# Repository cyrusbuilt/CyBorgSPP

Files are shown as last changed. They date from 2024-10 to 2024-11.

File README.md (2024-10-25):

# CyBorgSPP
Standard Parallel (Printer) Port adapter for [CyBorg](https://github.com/cyrusbuilt/CyBorg).

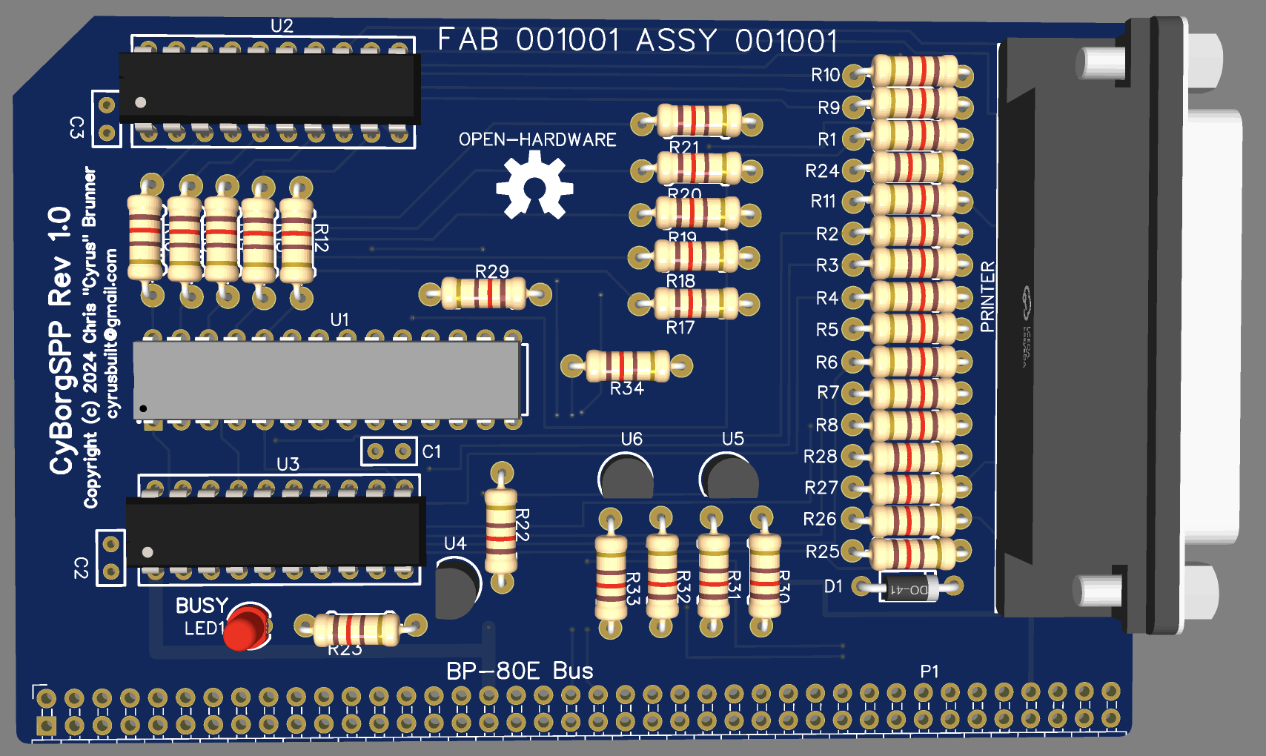
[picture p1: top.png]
CyBorgSPP


This is the first add-on card for CyBorg. The goal of this board is to provide an at least *somewhat* [IEEE 1284](https://en.wikipedia.org/wiki/IEEE_1284)-compliant parallel port interface. This board is currently only intended to operate in SPP (a.k.a. "Centronics" or "Compatibility") mode though it is possible to support other modes in via firmware modification (such as Nibble Mode). This board does not have an onboard MCU or any firmware of its own but instead relies on host firmware support.

## Implementation
This board is actually one of a few possible implementations of a parallel port for CyBorg:

1) Using a [Z80 PIO Chip](http://www.z80.info/zip/z80piomn.pdf). This would be a more "conventional" approach.

2) Using the I/O expansion lines (pins 41-56) of CyBorg's BP-80E bus. Pros: Eliminates a bunch of extra circuitry and the need for the 3.3V rail and would not consume an I2C address. Cons: Once initialized, CyBorg's IOEXP chip (and therefore *all* of the I/O expansion lines) on CyBorg's bus would become dedicated to the parallel (printer) port, which could interfere with the operation of any other boards on the bus that rely on those pins. At least until CyBorg is rebooted. There is also no easy way to detect whether or not the card is installed.

3) Using the I2C bus and a separate MCP23017 chip in conjunction with the rest of the SPP circuitry. Pros: Eliminates the reliance on CyBorg's onboard IOEXP and therefore doesn't need any of those I/O pins, so there is no interference with their operation. This also easy to detect whether or not the card is installed. Cons: Currently uses a fixed I2C address of 0x21 which means no other I2C device on the bus can be configured to use that address. However, this *does* essentially make the device 'plug and play' because this address would be known to CyBorg's firmware and therefore make it easy to detect if the card is installed and configure it.

This board went with option 3. It's worth noting that options 2 and 3 are a less direct route to implementing a parallel port since there are some additional steps that have to be taken vs. using a PIO chip. However, the performance *should* still be on par.

## Theory of Operation
On boot, CyBorg's firmware checks to see if CyBorgSPP is installed, and if so, enables support for it. If enabled, the following OpCodes become avaialable:

- OP_SPP_WR_INIT (0x11): Initialize the board. This really only needs to be done *once* sometime after boot before using any other related OpCodes.

- OP_SPP_WR_WRITE (0x12): Sends a byte to the printer. It's worth noting that this operation doesn't check the READY status of the printer beforehand so you should read status first to determine that if needed.

- OP_SPP_RD_READ (0x8A): Reads the status of the printer.

When an application writes one of the supported OpCodes to the Z80 bus, ViCREM's Virtual I/O engine intercepts it and then sends the appropriate I2C transactions to CyBorgSPP to carry out the requested operation.

## Form Factor
This board is currently in an [RC2014](https://rc2014.co.uk/1377/module-template/) form-factor, though this is subject to change since CyBorg was designed to be ATX-compliant. CyBorgSPP's form-factor will likely change to something similar to an ISA or PCI card with mounting holes for the slot plate, etc.

## Firmware
Support for CyBorgSPP is built-in to CyBorg's firmware running on the [ViCREM](https://github.com/cyrusbuilt/CyBorg-Northbridge) chip.

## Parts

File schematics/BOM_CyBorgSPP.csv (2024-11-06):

ID | Name | Designator | Footprint | Quantity | Manufacturer Part | Manufacturer | Supplier | Supplier Part | Price
1 | BP-80E Bus | P1 | PIN_HEADER_ANGLED_2X40_PITCH2.54MM | 1 | ReliaPro | 2.54mm 1x40T Female header | LCSC | C3410 | 0.313
2 | 4k7 | R34,R24,R25,R26,R27,R28,R29 | PKG-0.25W RESISTOR | 7 | MCF 0.25W 150R | MULTICOMP | Element14 | 9339175
3 | MCP23017-E/SP | U1 | DIP-28_L35.0-W6.5-P2.54-LS7.6-BL | 1 | MCP23017-E/SP | Microchip Tech | LCSC | C647352 | 1.751
4 | SN74LS244N | U3,U2 | DIP-20_L25.5-W10.0-P2.54-LS7.6-BL | 2 | SN74LS244N | TI(德州仪器) | LCSC | C352965 | 0.542
5 | X0325FT17B2H | PRINTER | DSUB-TH_25P-P2.77_C3123041 | 1 | X0325FT17B2H | XKB Connectivity(中国星坤) | LCSC | C18723072 | 2.897
6 | 1N4001 | D1 | DO-41_BD2.4-L4.7-P8.70-D0.9-RD | 1 | 1N4001 | LRC | LCSC | C82804
7 | 2N7000_C3281848 | U4,U5,U6 | TO-92-3_L4.9-W3.7-P1.27-L | 3 | 2N7000 | DIOTEC(德欧泰克) | LCSC | C3281848 | 0.075
8 | 33 | R1,R2,R3,R4,R5,R6,R7,R8,R9,R10,R11 | PKG-0.25W RESISTOR | 11 | MCF 0.25W 150R | MULTICOMP | Element14 | 9339175
9 | 220 | R22 | PKG-0.25W RESISTOR | 1 | MCF 0.25W 150R | MULTICOMP | Element14 | 9339175
10 | 680 | R23 | PKG-0.25W RESISTOR | 1 | MCF 0.25W 150R | MULTICOMP | Element14 | 9339175
11 | 1k | R12,R13,R14,R15,R16 | PKG-0.25W RESISTOR | 5 | MCF 0.25W 150R | MULTICOMP | Element14 | 9339175
12 | 10k | R17,R18,R19,R20,R21,R30,R31,R32,R33 | PKG-0.25W RESISTOR | 9 | MCF 0.25W 150R | MULTICOMP | Element14 | 9339175
13 | 0.1uF | C1,C2,C3 | CAP-RAD-2.54MM | 3
14 | BUSY | LED1 | LED-TH_BD3.0-P2.54-FD | 1 | 204-10SURD/S530-A3 | EVERLIGHT(亿光) | LCSC | C99772 | 0.029

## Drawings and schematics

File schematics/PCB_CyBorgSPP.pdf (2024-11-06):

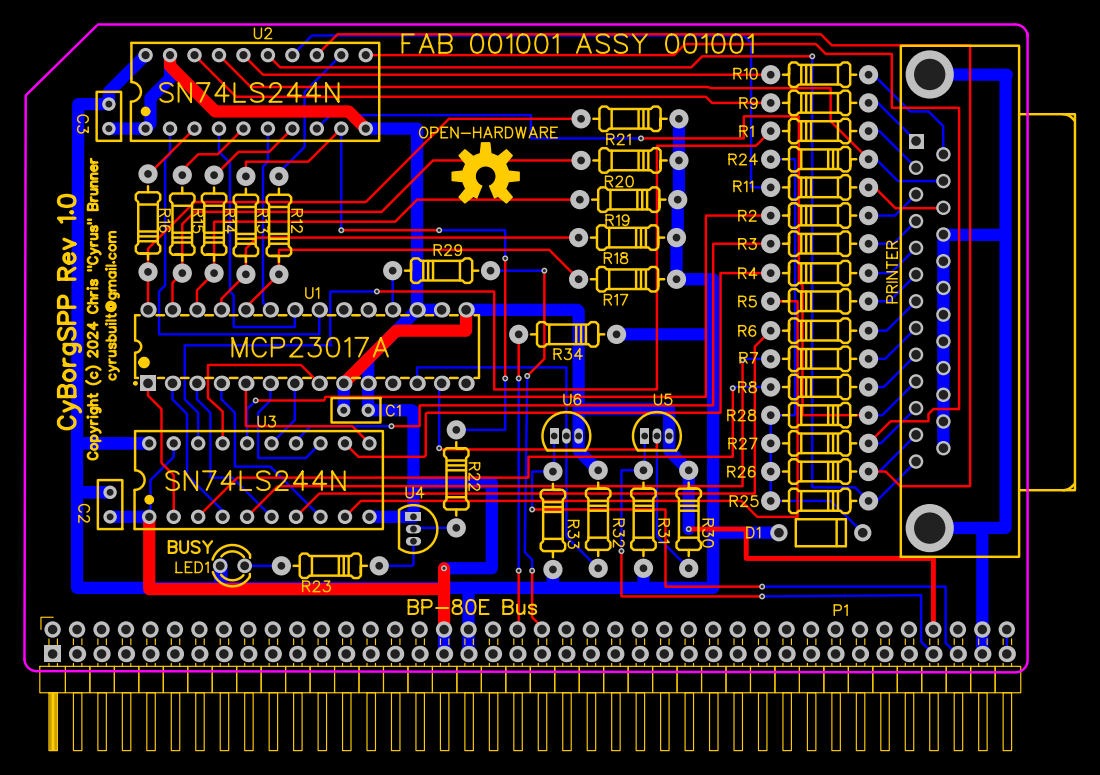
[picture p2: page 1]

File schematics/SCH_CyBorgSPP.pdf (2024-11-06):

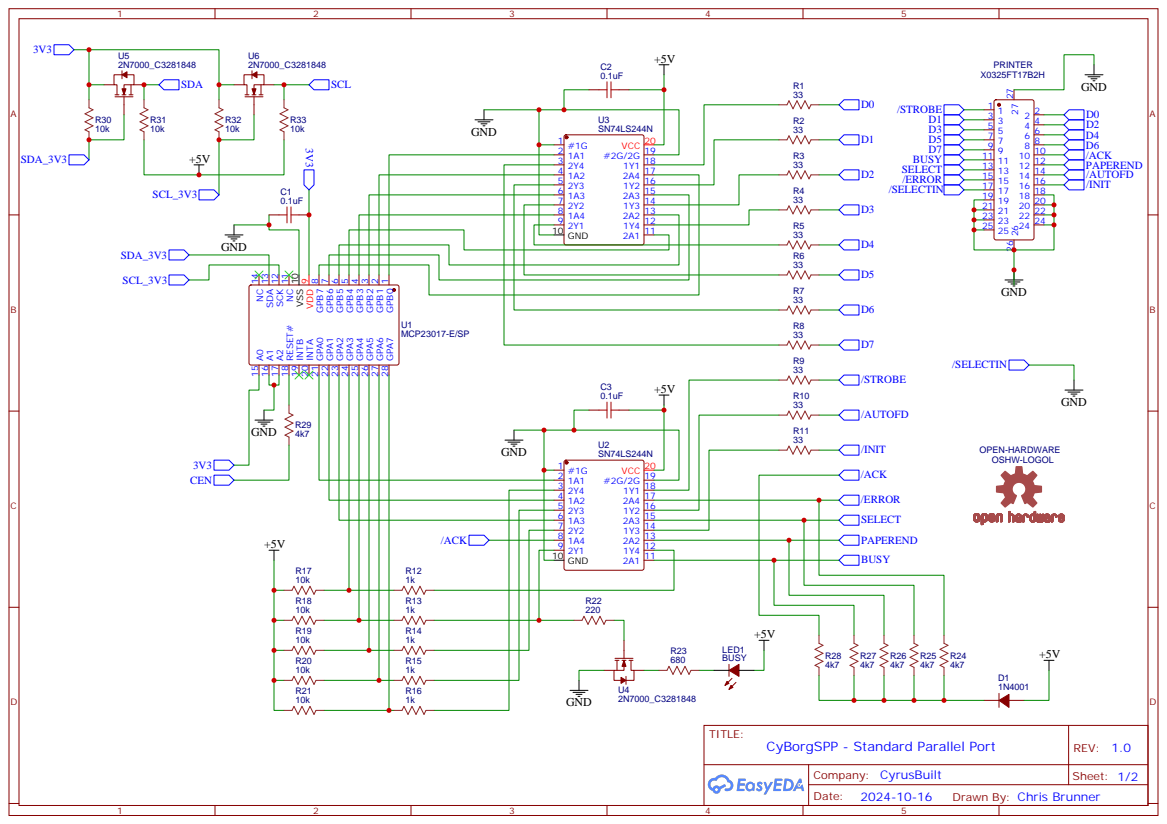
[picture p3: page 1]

9 VSS 10 NC 11 SCK 12 SDA 13 NC 14 A0 15 A1 16 A2 17 RESET# 18 INTB 19 INTA 20

Drawn By: Chris Brunner

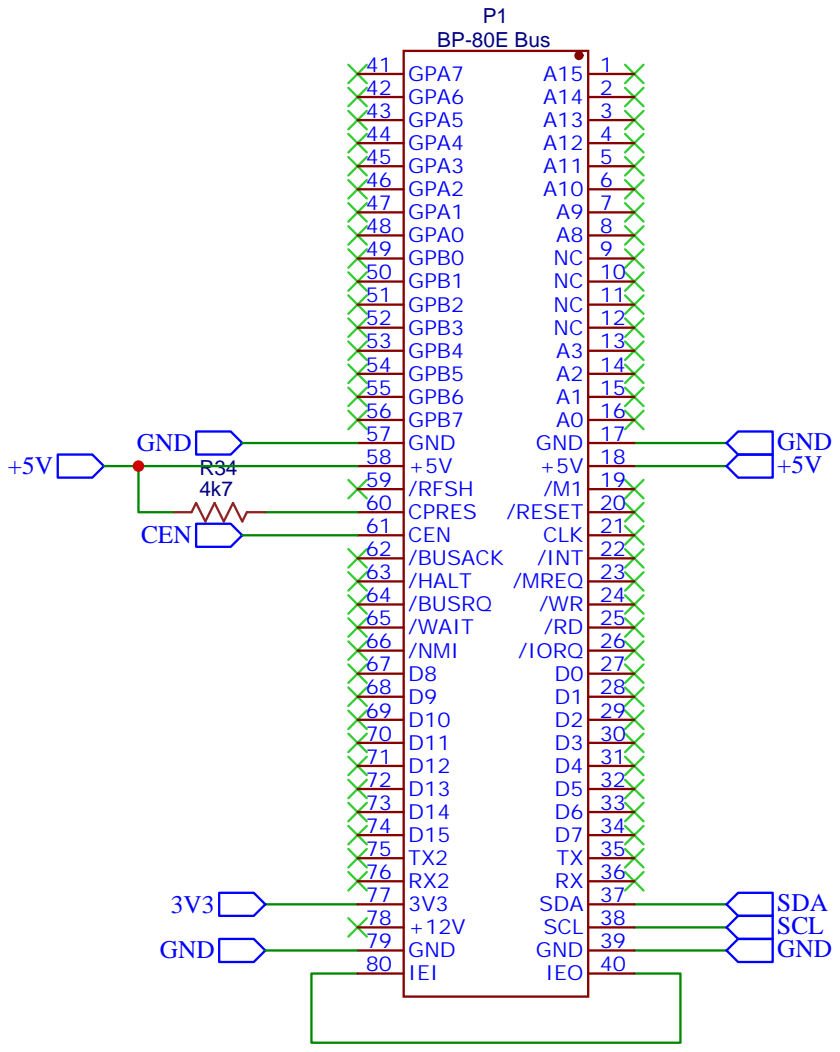
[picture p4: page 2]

Drawn By: Chris Brunner

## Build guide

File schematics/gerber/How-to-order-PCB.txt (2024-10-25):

How to Order PCB

Please refer to:
https://docs.easyeda.com/en/PCB/Order-PCB
